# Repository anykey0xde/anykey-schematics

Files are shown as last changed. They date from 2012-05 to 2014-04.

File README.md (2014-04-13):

NOTICE
======

This repository has moved.

Please find it here [https://github.com/presseverykey/everykey-schematics](https://github.com/presseverykey/everykey-schematics)

Just a quick notice to anyone potentially tracking these repositories: we've been informed that 
we are causing some confusion with an IT-system house named anykey GmbH.

In case you are looking for a company in Sankt Augustin, Germany
providing Oracle, EMC, or similar data center solutions, we apologize
for any inconvenience or confusion we may have caused. You want to be
[here](http://www.anykey.de/).

If you're looking for the Open Source ARM Cortex M3 embedded development
board, we've moved all our Open Source efforts to a new github account: [presseverykey](https://github.com/presseverykey).

Thanks and again, apologies for any confusion.

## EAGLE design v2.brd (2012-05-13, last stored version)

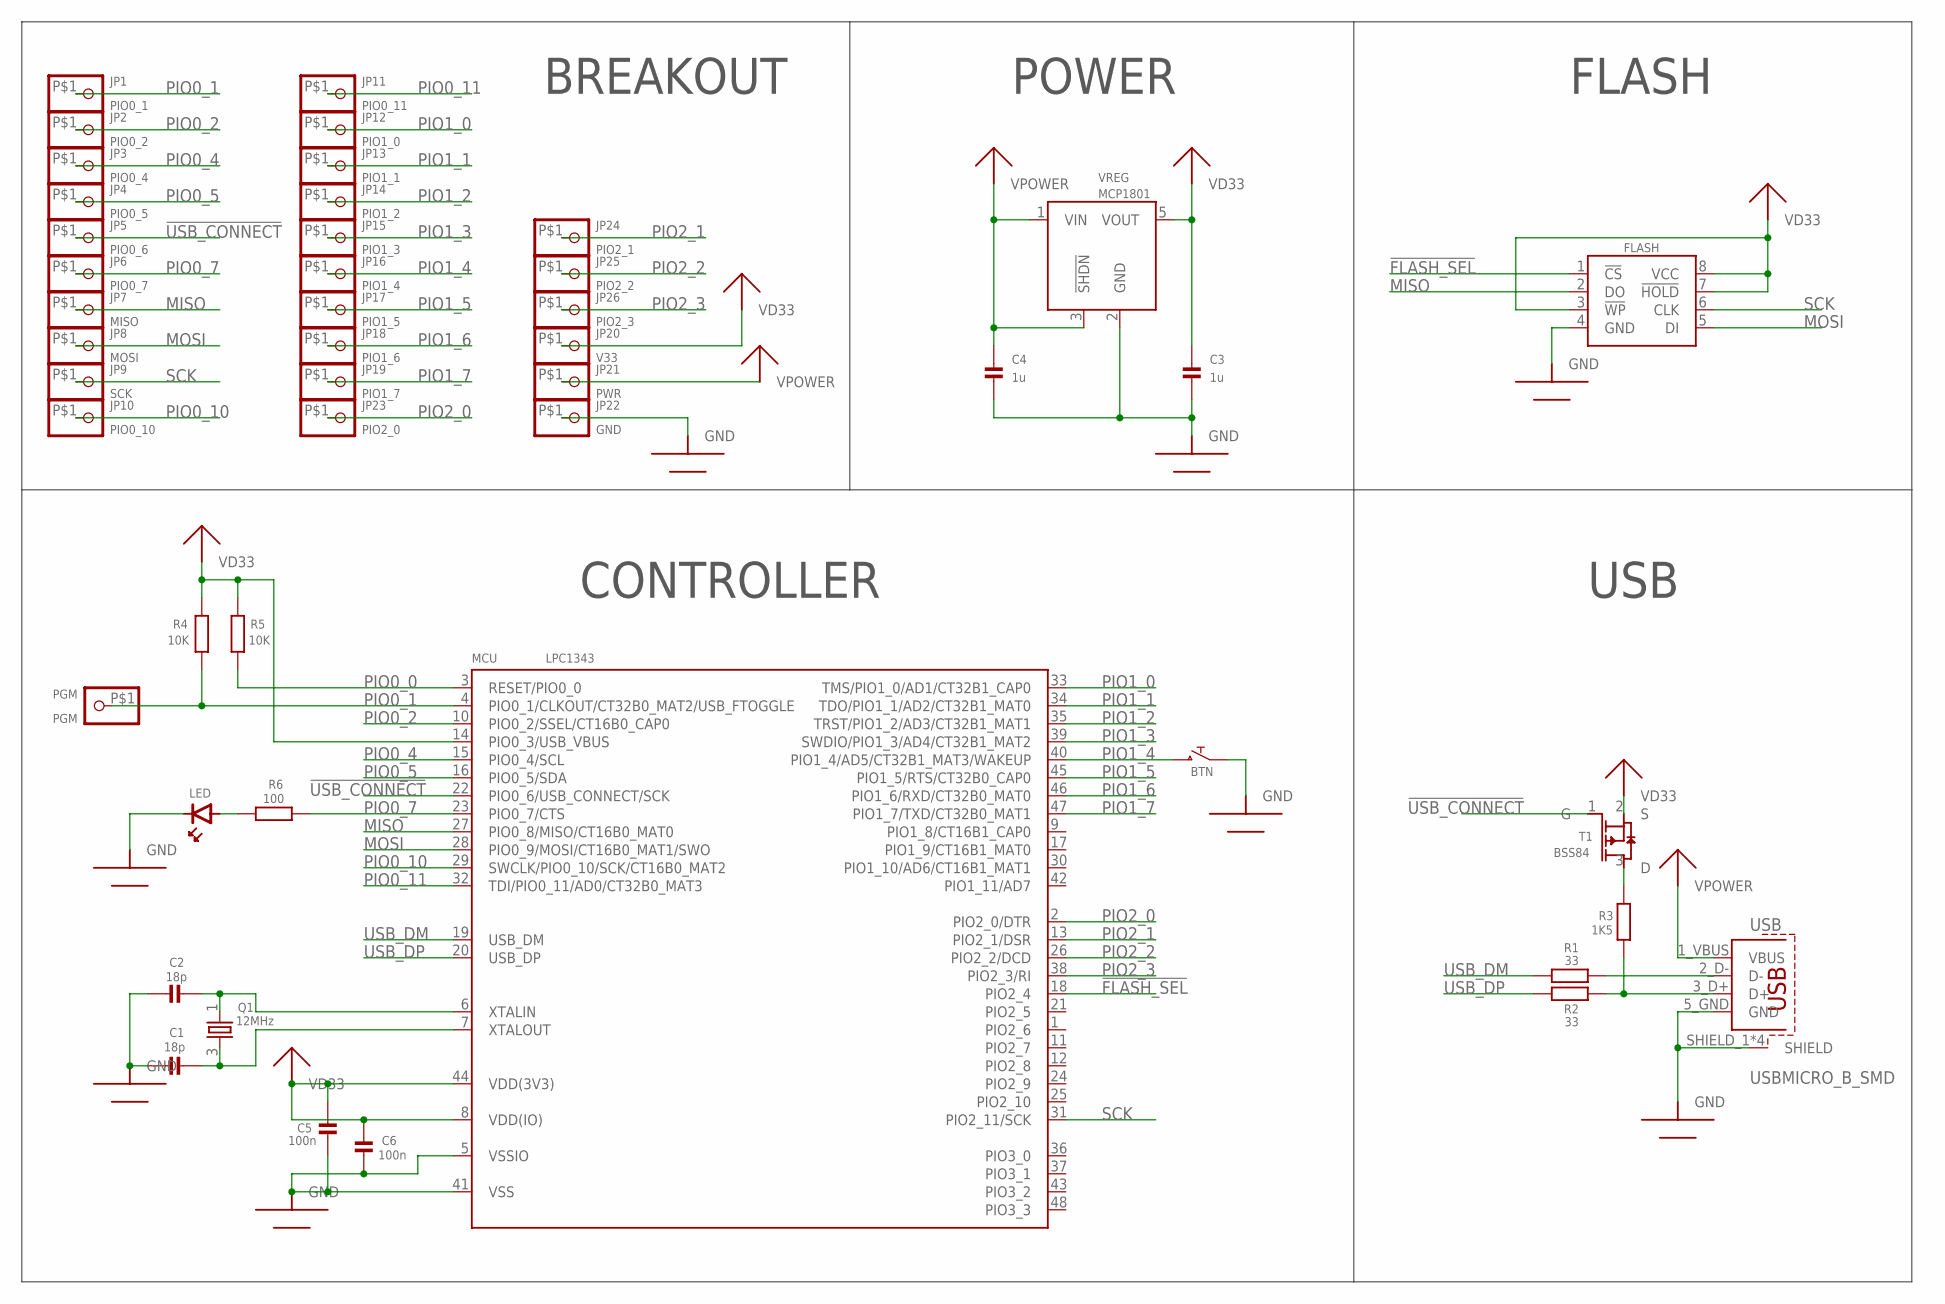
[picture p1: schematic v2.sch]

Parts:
BTN: PUSHBUTTONEVQP0; EVQP0
C1, C2: 18p; 0805_MICROMELF_COMBO
C3, C4: 1u; 0805_MICROMELF_COMBO
C5, C6: 100n; 0805_MICROMELF_COMBO
FLASH: SERIALFLASHSOIC8-150MIL; SOIC8-150MIL
JP1: PIO0_1; PCB_MEDIUM_RECT_PAD
JP2: PIO0_2; PCB_MEDIUM_RECT_PAD
JP3: PIO0_4; PCB_MEDIUM_RECT_PAD
JP4: PIO0_5; PCB_MEDIUM_RECT_PAD
JP5: PIO0_6; PCB_MEDIUM_RECT_PAD
JP6: PIO0_7; PCB_MEDIUM_RECT_PAD
JP7: MISO; PCB_MEDIUM_RECT_PAD
JP8: MOSI; PCB_MEDIUM_RECT_PAD
JP9: SCK; PCB_MEDIUM_RECT_PAD
JP10: PIO0_10; PCB_MEDIUM_RECT_PAD
JP11: PIO0_11; PCB_MEDIUM_RECT_PAD
JP12: PIO1_0; PCB_MEDIUM_RECT_PAD
JP13: PIO1_1; PCB_MEDIUM_RECT_PAD
JP14: PIO1_2; PCB_MEDIUM_RECT_PAD
JP15: PIO1_3; PCB_MEDIUM_RECT_PAD
JP16: PIO1_4; PCB_MEDIUM_RECT_PAD
JP17: PIO1_5; PCB_MEDIUM_RECT_PAD
JP18: PIO1_6; PCB_MEDIUM_RECT_PAD
JP19: PIO1_7; PCB_MEDIUM_RECT_PAD
JP20: V33; PCB_MEDIUM_RECT_PAD
JP21: PWR; PCB_MEDIUM_RECT_PAD
JP22: GND; PCB_MEDIUM_RECT_PAD
JP23: PIO2_0; PCB_MEDIUM_RECT_PAD
JP24: PIO2_1; PCB_MEDIUM_RECT_PAD
JP25: PIO2_2; PCB_MEDIUM_RECT_PAD
JP26: PIO2_3; PCB_MEDIUM_RECT_PAD
LED: 0805_POLAR
MCU: LPC1343; LQFP48
PGM: PGM; PCB_MEDIUM_RECT_PAD
Q1: 12MHz; ABM8G
R1, R2: 33; 0805_MICROMELF_COMBO
R3: 1K5; 0805_MICROMELF_COMBO
R4, R5: 10K; 0805_MICROMELF_COMBO
R6: 100; 0805_MICROMELF_COMBO
T1: BSS84; SOT23
USB: USBMICRO_B_SMD; MICRO_USB_B_SMD
VREG: MCP1801; SOT-23-5

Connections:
!FLASH_SEL: FLASH.1 (!CS), MCU.18 (PIO2_4)
!USB_CONNECT: JP5.P$1, MCU.22 (PIO0_6/USB_CONNECT/SCK), T1.1 (G)
GND: BTN.A (1), C1.1, C2.1, C3.2, C4.2, C5.2, C6.2, FLASH.4 (GND), JP22.P$1, LED.K (CATHODE), MCU.5 (VSSIO), MCU.41 (VSS), USB.5_GND (GND), USB.SHIELD_1 (SHIELD), USB.SHIELD_2 (SHIELD), USB.SHIELD_3 (SHIELD), USB.SHIELD_4 (SHIELD), VREG.2 (GND)
MISO: FLASH.2 (DO), JP7.P$1, MCU.27 (PIO0_8/MISO/CT16B0_MAT0)
MOSI: FLASH.5 (DI), JP8.P$1, MCU.28 (PIO0_9/MOSI/CT16B0_MAT1/SWO)
unnamed: C2.2, MCU.6 (XTALIN), Q1.1
unnamed: C1.2, MCU.7 (XTALOUT), Q1.3 (2)
unnamed: R3.1, T1.3 (D)
unnamed: R1.1, USB.2_D- (D-)
unnamed: LED.A (ANODE), R6.1
PIO0_0: MCU.3 (RESET/PIO0_0), R5.1
PIO0_1: JP1.P$1, MCU.4 (PIO0_1/CLKOUT/CT32B0_MAT2/USB_FTOGGLE), PGM.P$1, R4.1
PIO0_2: JP2.P$1, MCU.10 (PIO0_2/SSEL/CT16B0_CAP0)
PIO0_4: JP3.P$1, MCU.15 (PIO0_4/SCL)
PIO0_5: JP4.P$1, MCU.16 (PIO0_5/SDA)
PIO0_7: JP6.P$1, MCU.23 (PIO0_7/CTS), R6.2
PIO0_10: JP10.P$1, MCU.29 (SWCLK/PIO0_10/SCK/CT16B0_MAT2)
PIO0_11: JP11.P$1, MCU.32 (TDI/PIO0_11/AD0/CT32B0_MAT3)
PIO1_0: JP12.P$1, MCU.33 (TMS/PIO1_0/AD1/CT32B1_CAP0)
PIO1_1: JP13.P$1, MCU.34 (TDO/PIO1_1/AD2/CT32B1_MAT0)
PIO1_2: JP14.P$1, MCU.35 (TRST/PIO1_2/AD3/CT32B1_MAT1)
PIO1_3: JP15.P$1, MCU.39 (SWDIO/PIO1_3/AD4/CT32B1_MAT2)
PIO1_4: BTN.B (2), JP16.P$1, MCU.40 (PIO1_4/AD5/CT32B1_MAT3/WAKEUP)
PIO1_5: JP17.P$1, MCU.45 (PIO1_5/RTS/CT32B0_CAP0)
PIO1_6: JP18.P$1, MCU.46 (PIO1_6/RXD/CT32B0_MAT0)
PIO1_7: JP19.P$1, MCU.47 (PIO1_7/TXD/CT32B0_MAT1)
PIO2_0: JP23.P$1, MCU.2 (PIO2_0/DTR)
PIO2_1: JP24.P$1, MCU.13 (PIO2_1/DSR)
PIO2_2: JP25.P$1, MCU.26 (PIO2_2/DCD)
PIO2_3: JP26.P$1, MCU.38 (PIO2_3/RI)
SCK: FLASH.6 (CLK), JP9.P$1, MCU.31 (PIO2_11/SCK)
USB_D+: R2.1, R3.2, USB.3_D+ (D+)
USB_DM: MCU.19 (USB_DM), R1.2
USB_DP: MCU.20 (USB_DP), R2.2
VD33: C3.1, C5.1, C6.1, FLASH.3 (!WP), FLASH.7 (!HOLD), FLASH.8 (VCC), JP20.P$1, MCU.8 (VDD(IO)), MCU.14 (PIO0_3/USB_VBUS), MCU.44 (VDD(3V3)), R4.2, R5.2, T1.2 (S), VREG.5 (VOUT)
VPOWER: C4.1, JP21.P$1, USB.1_VBUS (VBUS), VREG.1 (VIN), VREG.3 (!SHDN)

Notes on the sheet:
FLASH
POWER
USB
BREAKOUT
CONTROLLER

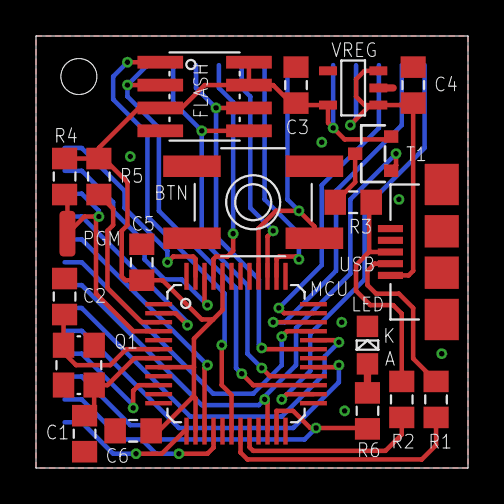
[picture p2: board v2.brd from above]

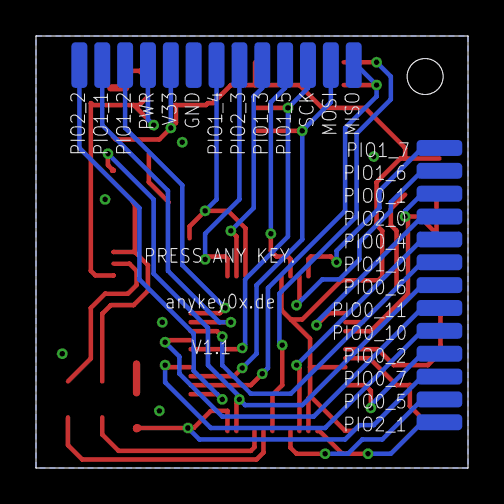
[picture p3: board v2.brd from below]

Board: 2 copper layers, 24.0 x 24.0 mm, 47 parts (26 on the bottom side), 36 nets.

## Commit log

2012-03-18 changed voltage regulator, routed more pins
    [v2.brd, v2.sch]
2012-03-18 vreg label 1801
    [v2.brd, v2.sch]
2012-03-19 moved via
    [v2.brd]
2012-03-19 Added drill hole, simplified routing, added version number on silkscreen, flash pinout fix, added softconnect transistor
    [v2.brd]
2012-03-19 Added softconnect transistor, vast cleanup
    [v2.sch]
2012-03-20 Changed mounting hole to drill, adjustments to meet Makepcb.com design limitations (i.e. move oscillator), some more trace straightening
    [v2.brd]
2012-03-20 Board adjustments to comply with MakePCB.com
    [v2.brd, v2.sch]
2012-03-20 Gerber files for v1.0 PCB order
2012-03-23 Added button outline (to get a better impression of space inside the device)
    [v2.brd]
2012-05-13 Lessons learned: Larger font, reversed USB Pullup, clearer silkscreen, wider and rounded solder pads
    [v2.brd, v2.sch]
2012-08-15 pdf and png version of schematics
2014-04-13 update notice
    [v2.brd, v2.sch]
